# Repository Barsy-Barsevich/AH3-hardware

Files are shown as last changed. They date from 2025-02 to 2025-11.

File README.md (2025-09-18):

# AH3 hardware repository

- [AH3 on-board software repository](https://github.com/Barsy-Barsevich/AH3-software)
- [AH3 Arduino library](https://github.com/Barsy-Barsevich/AH3_Barsotion)

---
## ⚡️Manual
- [AH3 software 2nd revision manual (newest release)](./Manual/AH3_soft_revision_2_manual.pdf)
- [AH3 software 1st revision manual](./Manual/AH3_soft_revision_1_manual.pdf)
- [AH3 software 1st revision manual (preliminary edition)](./Manual/AH3_soft_revision_1_manual_preliminary_edition.pdf)

---
## ⚡️Previous AHx boards
- [AH1](https://github.com/Barsy-Barsevich/Barsotion-AH1)
- [AH2](https://github.com/Barsy-Barsevich/Barsotion-AH2)

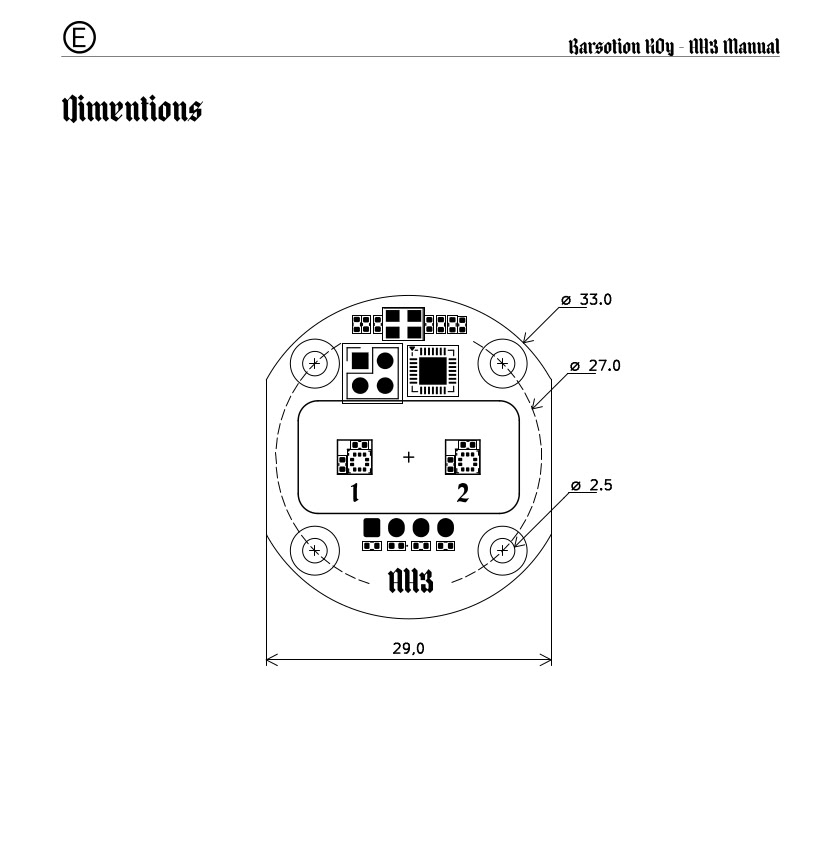
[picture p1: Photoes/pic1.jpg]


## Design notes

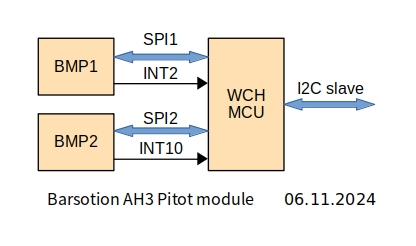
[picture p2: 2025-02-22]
Schematic/Barsotion_AH3_BlokScheme.jpg

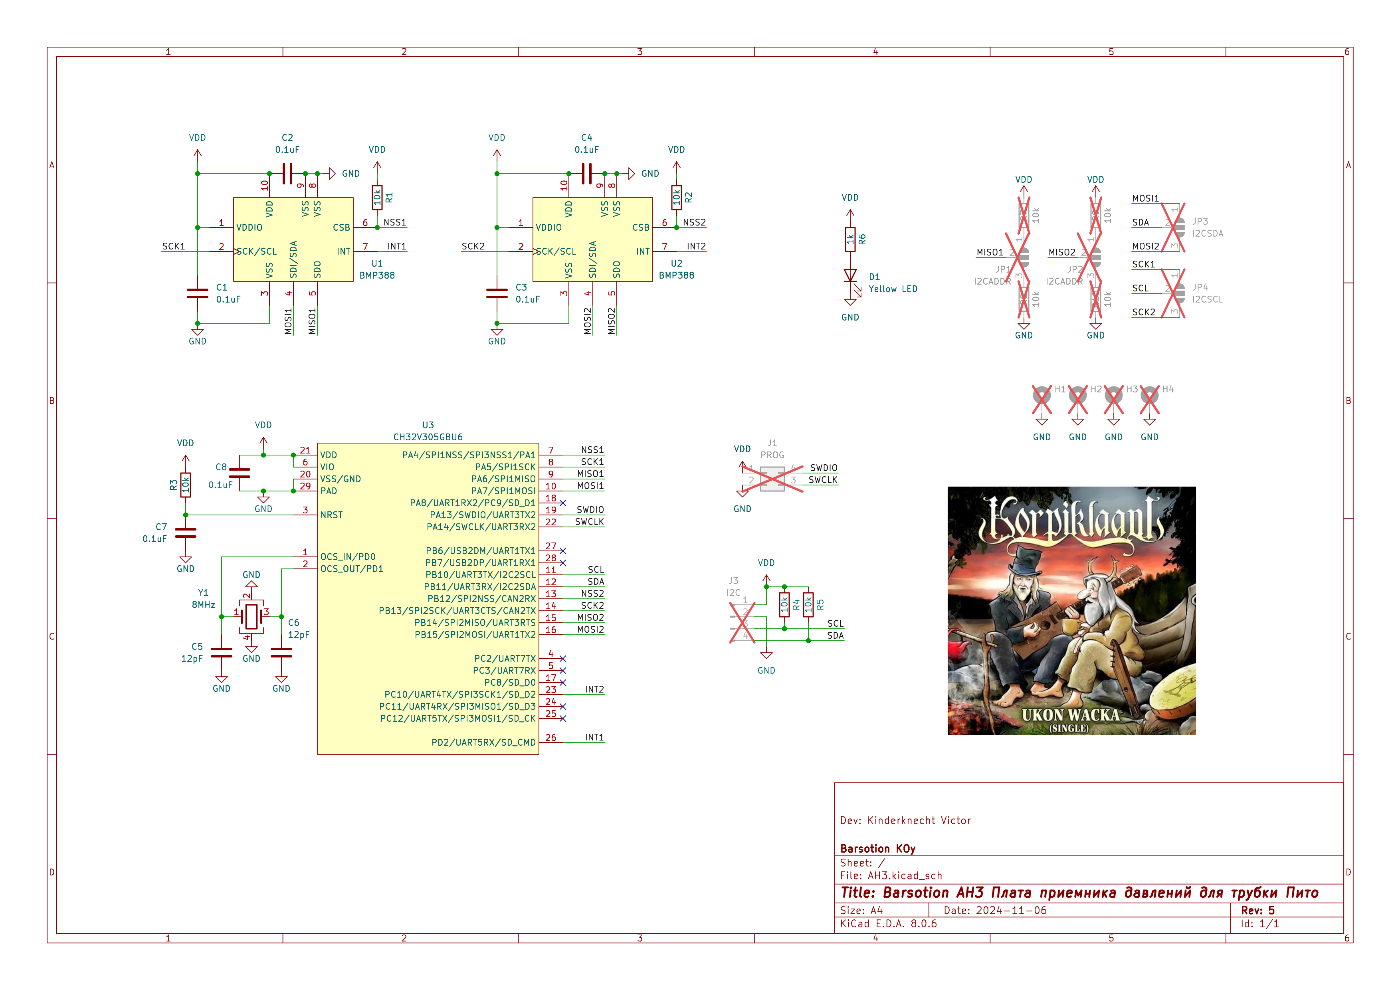
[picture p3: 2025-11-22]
Schematic/AH3v5_Schematic.png

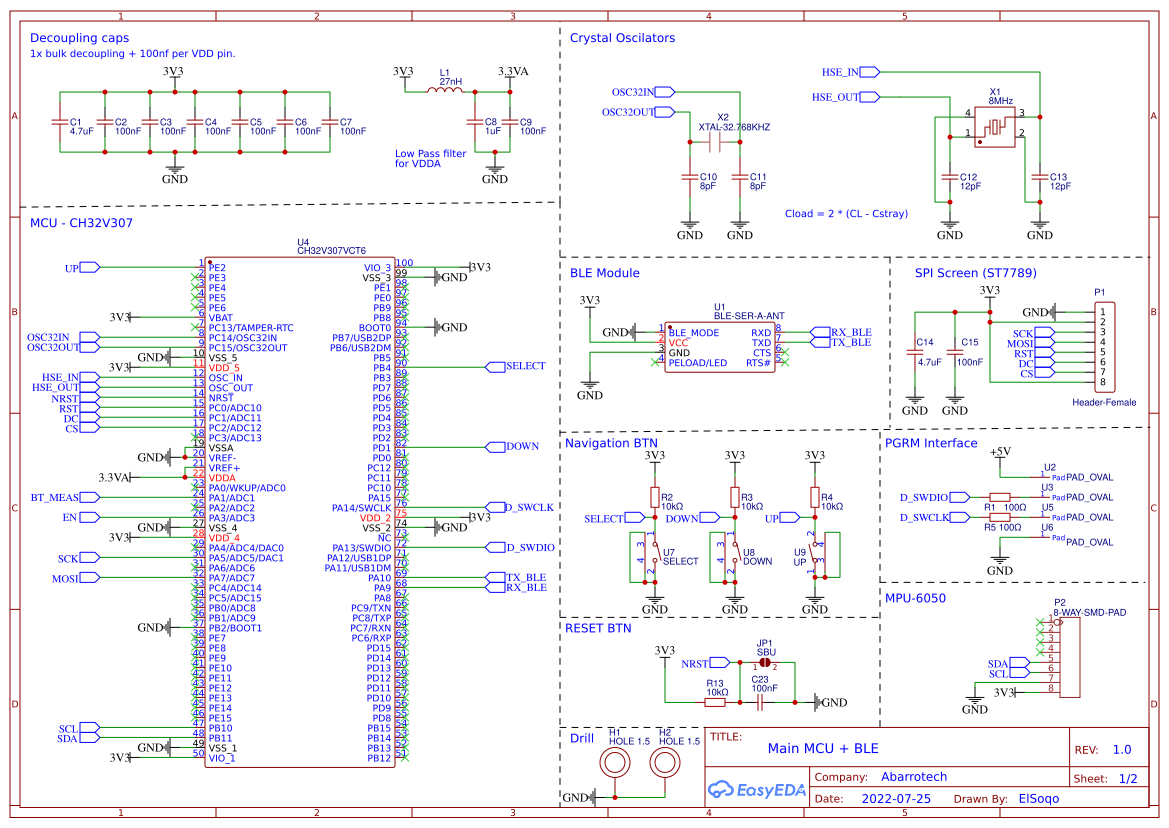
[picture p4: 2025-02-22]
Ref/CH32V307_REF1.png

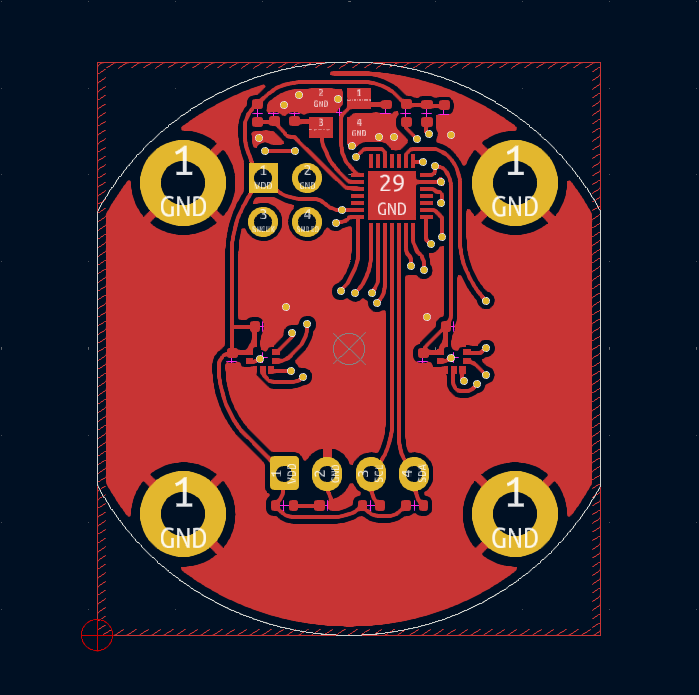
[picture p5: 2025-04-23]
Topology/AH3 Layer 1.png

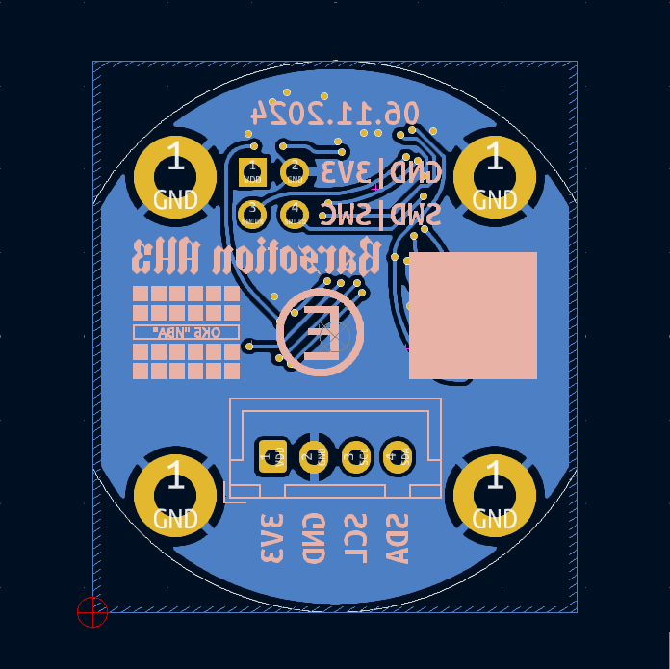
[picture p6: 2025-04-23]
Topology/AH3 Bottom.png

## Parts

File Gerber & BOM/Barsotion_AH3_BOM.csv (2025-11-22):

Reference | Value | Datasheet | Footprint | Qty | DNP
C1,C2,C3,C4,C7,C8 | 0.1uF | ~ | Capacitor_SMD:C_0402_1005Metric | 6
C5,C6 | 12pF | ~ | Capacitor_SMD:C_0402_1005Metric | 2
D1 | Yellow LED | ~ | LED_SMD:LED_0402_1005Metric | 1
R1,R2,R3,R4,R5 | 10k | ~ | Resistor_SMD:R_0402_1005Metric | 5
R6 | 1k | ~ | Resistor_SMD:R_0402_1005Metric | 1
U1,U2 | BMP388 | https://pdf1.alldatasheet.com/datasheet-pdf/download/1132070/BOSCH/BMP388.html | CustomPackage:BMP388 | 2
U3 | CH32V305GBU6 |  | Package_DFN_QFN:QFN-28-1EP_4x4mm_P0.4mm_EP2.8x2.8mm | 1
Y1 | 8MHz | https://www.lcsc.com/datasheet/lcsc_datasheet_2403291505_YXC-Crystal-Oscillators-X32258MOB4SI_C2682775.pdf | Crystal:Crystal_SMD_3225-4Pin_3.2x2.5mm | 1

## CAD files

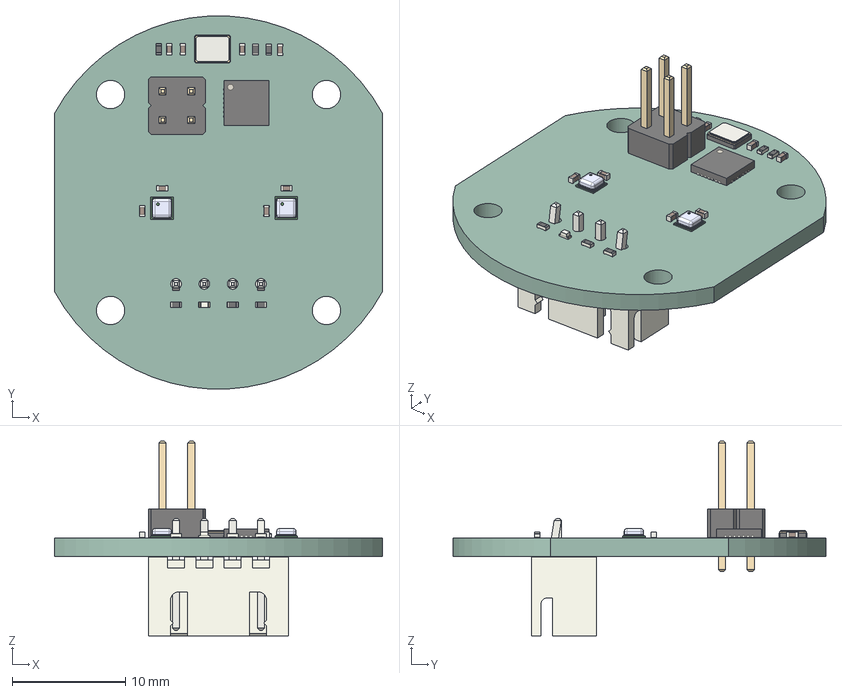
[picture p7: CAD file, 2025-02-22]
Step/AH3_v4.step
29.0 x 33.0 x 17.2 mm
QFN-28-1EP_4x4mm_Pitch0.4mm
C_0402_1005Metric x 8
R_0402_1005Metric x 6
BMP388 x 2
PinHeader_2x02_P254mm_Vertical
LED_0402_1005Metric
Crystal_SMD_3225-4Pin_3.2x2.5mm
JST_B4B_XH_A
AH3_PCB

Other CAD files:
Step/AH3_v2.step
Step/AH3_v01.step

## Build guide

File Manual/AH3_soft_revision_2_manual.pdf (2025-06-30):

## AH3 air speedometer module

## Software 2nd revision manual

Barsotion KOy, 2025

Barsotion KOy - AH3 Manual 2nd revision

## Table of contents

2

2

Barsotion KOy - AH3 Manual 2nd revision

## Overview

The Barsotion AH3 airspeed module is an I2C device created to measure atmosphere pressure, airspeed, vertical speed, altitude, air temperature.
This documents describes the work with the AH3 boards with the 1st version of processing microcontroller software.

Structural organization
The module contains 2 BMP388 temperature and pressure sensors and CH32V305 processing microcontroller. The microcontroller reads rata from the sensors via SPI, process it and can give the results to host via I2C interface.

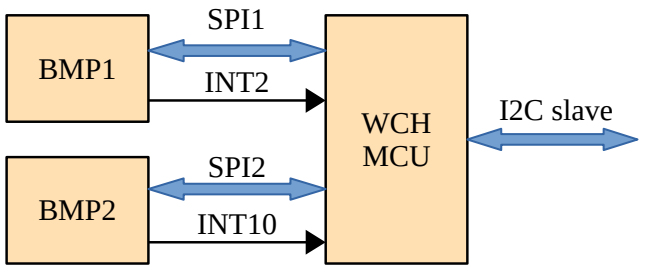
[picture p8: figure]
BMP1; BMP2; WCH MCU; SPI1; SPI2; I2C slave; INT2; INT10

The BMP388 sensors are numerated: 1 and 2. The 1st sensor is a static pressure and temperature sensor, the 2nd is a dynamic sensor.
The microcontroller process the data: it calculates altitude according the static sensor barometer data, differentiates altitude for getting vertical speed, also it can analyze the difference in static and dynamic pressures to get an air speed value. The read temperature and pressure data can be filtered by 1-dimentional Kalman filters. The calibration methods allows to get the filter start parameters and provide the quality of outgoing air speed data.

Future updates (TODO)
The host can set up the AH3 module depending of it’s needs. Both of static and dynamic sensors can be disabled if it is necessary. In this (1st) software version host cannot power down any BMP388 sensor, it will still work if even the according enable bit is cleared, so disabling the BMP388 sensor does not affect on the power consumption. However the sensor power down option while disabled will be added in future software versions.

3

Barsotion KOy - AH3 Manual 2nd revision

The BMP388 sensors interrupt request signals are wired to the microcontroller’s GPIOs. Theoretically, the data reading can be processed via interrupts, but this software does not use it. The program reads the BMP388s’ interrupt status registers waiting for the data ready bits setting up. The sensors interrupt handling will be added in future versions, that can also reduce the power consumption.

Sensors settings
The BMP388 maximum ODR value is 200 Hz. The processing microcontroller uses this ODR for providing fast reaction on the external events.
The software does not use the BMP388’s data oversampling function. The oversampling can help to get more accurate output value, however it strongly limits the real output data rate.
The software uses BMP388’s IIR-filter with coefficient 7. It is a compromise between data rate and accuracy.
The host cannot configure the BMP388 sensors settings for this software revision.

Applications
This airspeed module can be used in copters, model rockets, little airplanes, automobiles and other mobile machines and devices.

4

Barsotion KOy - AH3 Manual 2nd revision

## Device characteristics

Parameter | Min | Nom | Max
Power supply, V | 3.0 | 3.3 | 3.6
Power consimption, mA | - | - | 16
I2C logic level, V | - | 3.3 | 5
I2C speed, kHz | - | 400 | 1000
Main CPU frequency, MHz | - | 96 | -
BMP388 sensor ODR, Hz | - | 200 | -
Pressure oversampling | - | 1x | -
Temperature oversampling | - | 1x | -
BMP388 IIR-filter coefficient | - | 7 | -

5

Barsotion KOy - AH3 Manual 2nd revision

## Register map

Name | Address | Description
WHO_AM_I | 0x00 | Always read as 0x74.
SOFT_REV | 0x01 | Soft revision code, for this version 0x02.
ERR | 0x02 | Error status register, see ERR.
CONFIG | 0x03 | Config register, see CONFIG.
STATUS | 0x04 | Status flag register, see STATUS.
TEMP1_0 | 0x05 | Static sensor temperature data, 4-byte float.
TEMP1_1 | 0x06
TEMP1_2 | 0x07
TEMP1_3 | 0x08
PRES1_0 | 0x09 | Static sensor pressure data, 4-byte float.
PRES1_1 | 0x0A
PRES1_2 | 0x0B
PRES1_3 | 0x0C
TEMP2_0 | 0x0D | Dynamic sensor temperature data, 4-byte float.
TEMP2_1 | 0x0E
TEMP2_2 | 0x0F
TEMP2_3 | 0x10
PRES2_0 | 0x11 | Dynamic sensor pressure data, 4-byte float.
PRES2_1 | 0x12
PRES2_2 | 0x13
PRES2_3 | 0x14
ASPEED_0 | 0x15 | Calculated air speed value, 4-byte float.
ASPEED_1 | 0x16
ASPEED_2 | 0x17
ASPEED_3 | 0x18
ALT_0 | 0x19 | Calculated altitude.
ALT_1 | 0x1A
ALT_2 | 0x1B
ALT_3 | 0x1C

6

Barsotion KOy - AH3 Manual 2nd revision

VSPEED_0 | 0x1D | Calculated vertical speed.
VSPEED_1 | 0x1E
VSPEED_2 | 0x1F
VSPEED_3 | 0x20
WHO_AM_I
7 | 6 | 5 | 4 | 3 | 2 | 1 | 0
0 | 1 | 1 | 1 | 0 | 1 | 0 | 0
The register is always read as 0x74.
SOFT_REV
7 | 6 | 5 | 4 | 3 | 2 | 1 | 0
0 | 0 | 0 | 0 | 0 | 0 | 0 | 1
The register is always read as 0x01.
ERR
7 | 6 | 5 | 4 | 3 | 2 | 1 | 0
Reserved | | | ERR_BMP2 _DATA | ERR_BMP1 _DATA | ERR_I2C | ERR_BMP2 _INIT | ERR_BMP1 _INIT
- ERR_BMP1_INIT: Static sensor initialization error.
- ERR_BMP2_INIT: Dynamic sensor initialization error.
- ERR_I2C: I2C protocol error.
- ERR_BMP1_DATA: Static sensor data incorrect value error (is not supported in this version).
- ERR_BMP2_DATA: Dynamic sensor data incorrect value error (is not supported in this version).
CONFIG
7 | 6 | 5 | 4 | 3 | 2 | 1 | 0
ASPD_CAL | ASPD_EN | BMP2_CAL | BMP1_CAL | BMP2_FILT | BMP1_FILT | BMP2_EN | BMP1_EN
- BMP1_EN: Set to 1 enables static sensor data reading.
- BMP2_EN: Set to 1 enables dynamic sensor data reading.
- BMP1_FILT: Set to 1 enables static sensor data filtering by 1-dimentional Kalman algorithm (the option is available only after calibrating).
- BMP2_FILT: Set to 1 enables dynamic sensor data filtering by 1-dimentional Kalman algorithm (the option is available only after calibrating).
- BMP1_CAL: Set to starts static sensor calibration. Cleared automatically after the calibration has finished. While the calibration time goes on, the BUSY bit in STATUS register is set to 1.

7

Barsotion KOy - AH3 Manual 2nd revision

- BMP2_CAL: Set to starts dynamic sensor calibration. Cleared automatically after the calibration has finished. While the calibration time goes on, the BUSY bit in STATUS register is set to 1.
- ASPD_EN: Set to 1 enables air speed calculations. The option is only available if both of BMP1_EN and BMP2_EN bits are set to 1. Note that the barometer sensors should be calibrated before air speed calculations starts, in the other way the output data will contain a non-normed offset.
- ASPD_CAL: Set to 1 starts the airspeed calibrating.
STATUS
7 | 6 | 5 | 4 | 3 | 2 | 1 | 0
BUSY | ASPD_DRDY | Reserved | | | | BMP2_DRDY | BMP1_DRDY
- BMP1_DRDY: is set to 1 when the first sensor temperature and pressure data are ready to be read. The bit is cleared automatically when the STATUS register is read.
- BMP2_DRDY: is set to 1 when the second sensor temperature and pressure data are ready to be read. The bit is cleared automatically when the STATUS register is read.
- ASPD_DRDY: is set to 1 when the air speed value is ready to be read. The bit is cleared automatically when the STATUS register is read.
- BUSY: is set when any sensor is calibrating. While the calibrating time the AH3 module do not update other sensor output data and air speed calculations are stopped too. The bit is cleared automatically when the calibration done.
Output data format
All the output data are in the standard IEEE-754 4-byte float format, used in the C language. That means:
0

th register:
7 | 6 | 5 | 4 | 3 | 2 | 1 | 0
Mantissa | | | | | | | Man. LSb
1

st register:
15 | 14 | 13 | 12 | 11 | 10 | 8 | 7
Mantissa
2

nd register:
23 | 22 | 21 | 20 | 19 | 18 | 17 | 16
Exp. LSb | Man. MSb | Mantissa
3

rd register:
31 | 30 | 29 | 28 | 27 | 26 | 25 | 24
Sign | Exp. MSb | Exponent

8

Barsotion KOy - AH3 Manual 2nd revision

## Initialization algorithm (air speed calculation enable)

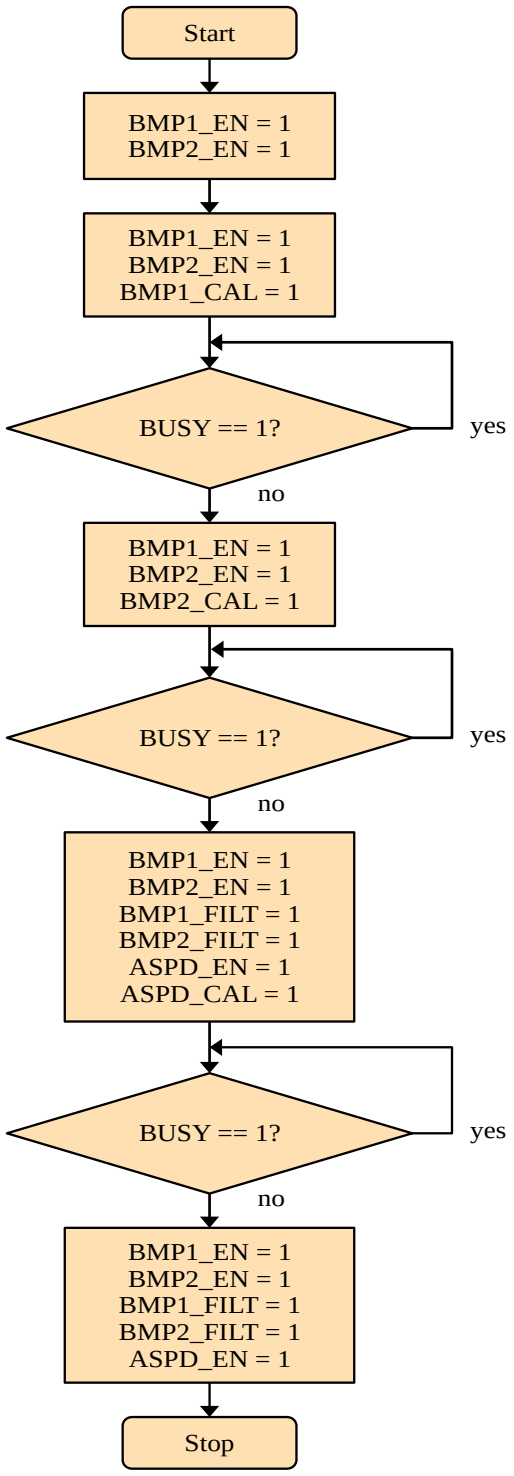
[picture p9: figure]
BMP1_EN = 1 BMP2_EN = 1; BMP1_EN = 1 BMP2_EN = 1 BMP1_CAL = 1; BUSY == 1?; BMP1_EN = 1 BMP2_EN = 1 BMP2_CAL = 1; BMP1_EN = 1 BMP2_EN = 1 BMP1_FILT = 1 BMP2_FILT = 1 ASPD_EN = 1 ASPD_CAL = 1; BMP1_EN = 1 BMP2_EN = 1 BMP1_FILT = 1 BMP2_FILT = 1 ASPD_EN = 1; yes; Start; Stop

9

## Dimentions

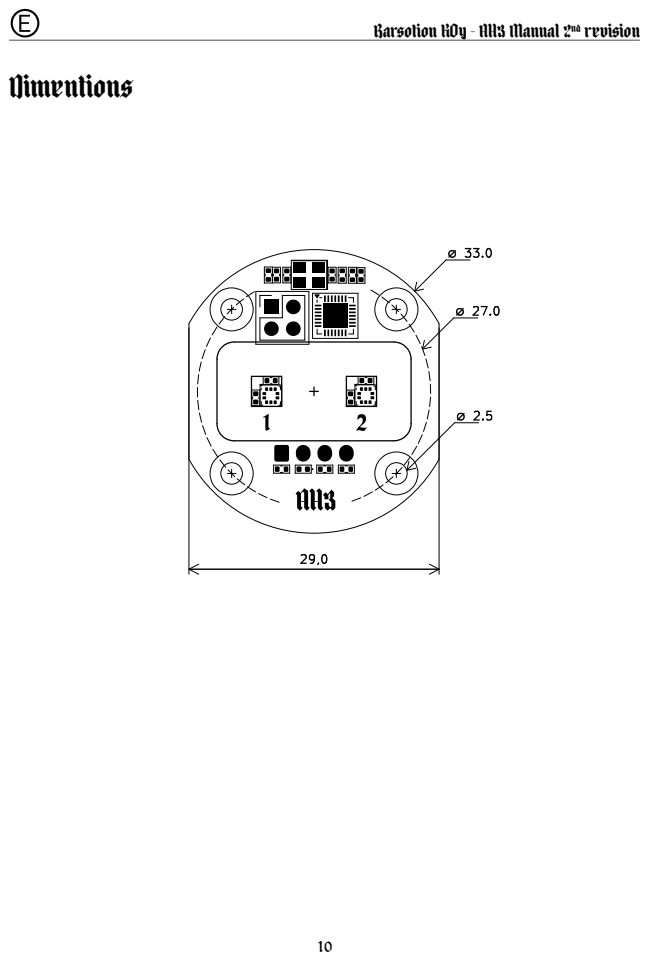
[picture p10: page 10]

Barsotion KOy - AH3 Manual 2nd revision

2

## nd revision

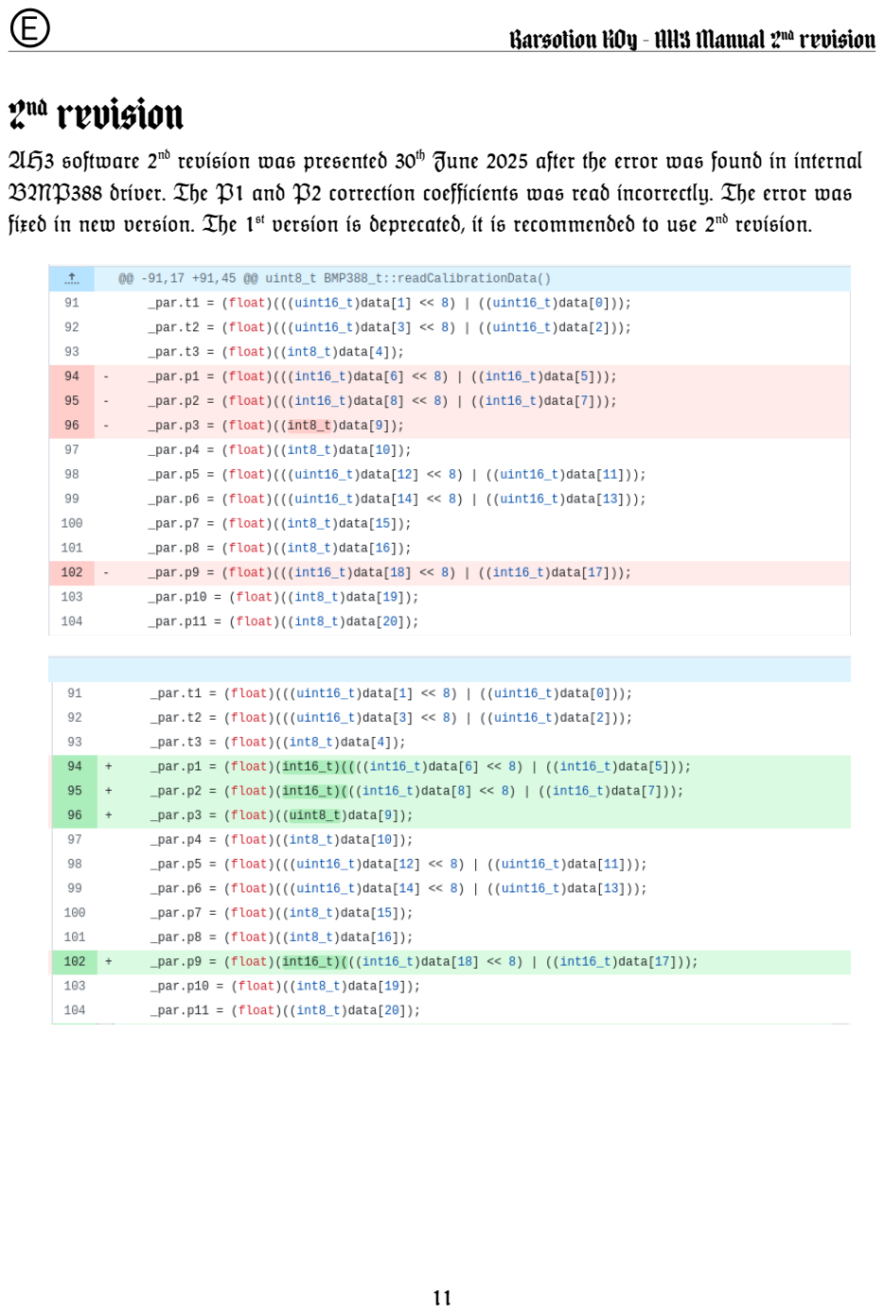
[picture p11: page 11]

Barsotion KOy - AH3 Manual 2nd revision

AH3 software 2nd revision was presented 30th June 2025 after the error was found in internal BMP388 driver. The P1 and P2 correction coefficients was read incorrectly. The error was fixed in new version. The 1st version is deprecated, it is recommended to use 2nd revision.

11

Barsotion KOy - AH3 Manual 2nd revision

## Revision history

Date | Modification
Jun 30, 2025 | BMP388 driver bug fixed.
Mar 8, 2025 | New dimention picture, revision history addition.
Jan 21, 2025 | Document creation.

12

Barsotion KOy - AH3 Manual 2nd revision

## Contacts

If you have any questions, feel free to write via email or Telegram. Email: barsotion@yandex.ru
Telegram: @barsybarsevich

13

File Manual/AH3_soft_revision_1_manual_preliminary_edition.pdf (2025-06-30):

## AH3 air speedometer module

## Software 1st revision manual

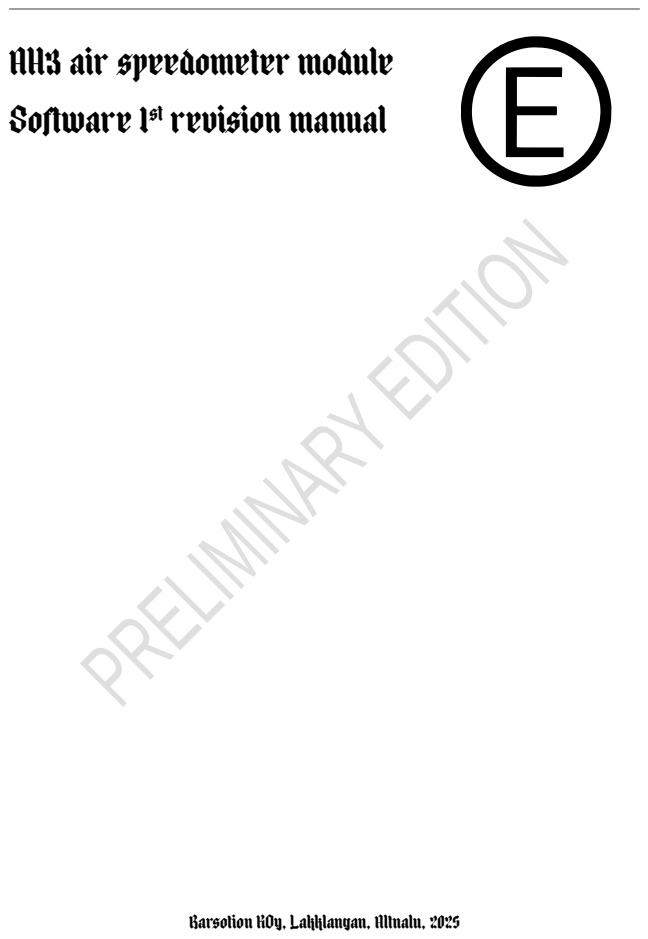
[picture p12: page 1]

Barsotion KOy, Lakklangan, Altnalu, 2025

## Table of contents

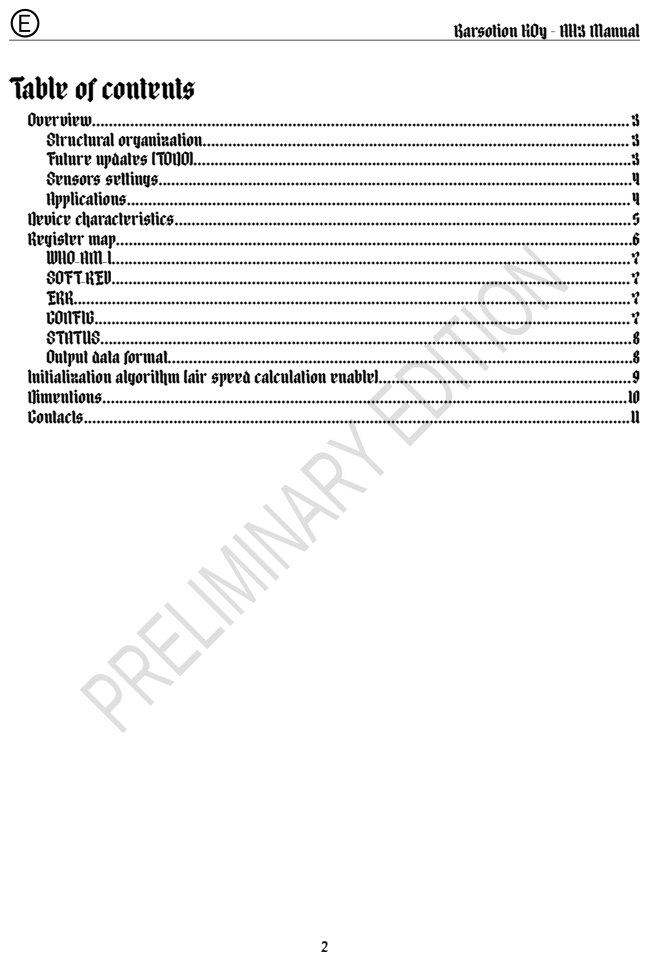
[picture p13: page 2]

Barsotion KOy - AH3 Manual

Barsotion KOy - AH3 Manual

## Overview

The Barsotion AH3 airspeed module is an I2C device created to measure atmosphere pressure, airspeed, vertical speed, altitude, air temperature.
This documents describes the work with the AH3 boards with the 1st version of processing microcontroller software.

Structural organization
The module contains 2 BMP388 temperature and pressure sensors and CH32V305 processing microcontroller. The microcontroller reads rata from the sensors via SPI, process it and can give the results to host via I2C interface.

The BMP388 sensors are numerated: 1 and 2. The 1st sensor is a static pressure and temperature sensor, the 2nd is a dynamic sensor.
The microcontroller process the data: it calculates altitude according the static sensor barometer data, differentiates altitude for getting vertical speed, also it can analyze the difference in static and dynamic pressures to get an air speed value. The read temperature and pressure data can be filtered by 1-dimentional Kalman filters. The calibration methods allows to get the filter start parameters and provide the quality of outgoing air speed data.

Future updates (TODO)
The host can set up the AH3 module depending of it’s needs. Both of static and dynamic sensors can be disabled if it is necessary. In this (1st) software version host cannot power down any BMP388 sensor, it will still work if even the according enable bit is cleared, so disabling the BMP388 sensor does not affect on the power consumption. However the sensor power down option while disabled will be added in future software versions.

3

BMP1

BMP2

WCH
MCU

SPI1

SPI2

I2C slave

INT2

INT10

Barsotion KOy - AH3 Manual

The BMP388 sensors interrupt request signals are wired to the microcontroller’s GPIOs. Theoretically, the data reading can be processed via interrupts, but this software does not use it. The program reads the BMP388s’ interrupt status registers waiting for the data ready bits setting up. The sensors interrupt handling will be added in future versions, that can also reduce the power consumption.

Sensors settings
The BMP388 maximum ODR value is 200 Hz. The processing microcontroller uses this ODR for providing fast reaction on the external events.
The software does not use the BMP388’s data oversampling function. The oversampling can help to get more accurate output value, however it strongly limits the real output data rate.
The software uses BMP388’s IIR-filter with coefficient 7. It is a compromise between data rate and accuracy.
The host cannot configure the BMP388 sensors settings for this software revision.

Applications
This airspeed module can be used in copters, model rockets, little airplanes, automobiles and other mobile machines and devices.

4

## Device characteristics

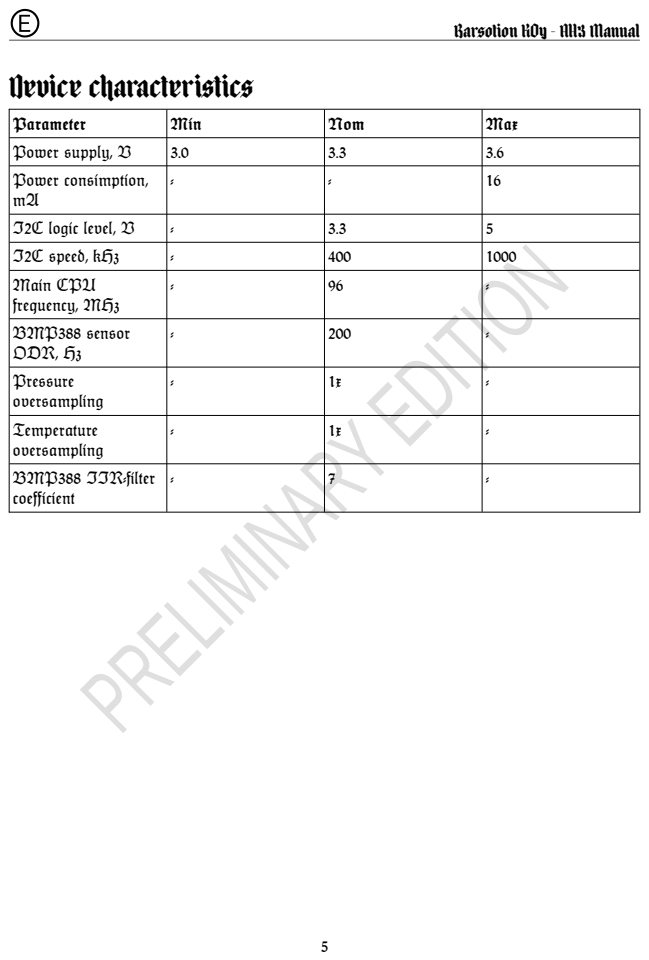
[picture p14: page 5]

Barsotion KOy - AH3 Manual

Parameter | Min | Nom | Max
Power supply, V | 3.0 | 3.3 | 3.6
Power consimption, mA | - | - | 16

I2C logic level, V | - | 3.3 | 5
I2C speed, kHz | - | 400 | 1000
Main CPU frequency, MHz | - | 96 | -

BMP388 sensor ODR, Hz | - | 200 | -

Pressure oversampling | - | 1x | -

Temperature oversampling | - | 1x | -

BMP388 IIR-filter coefficient | - | 7 | -

## Register map

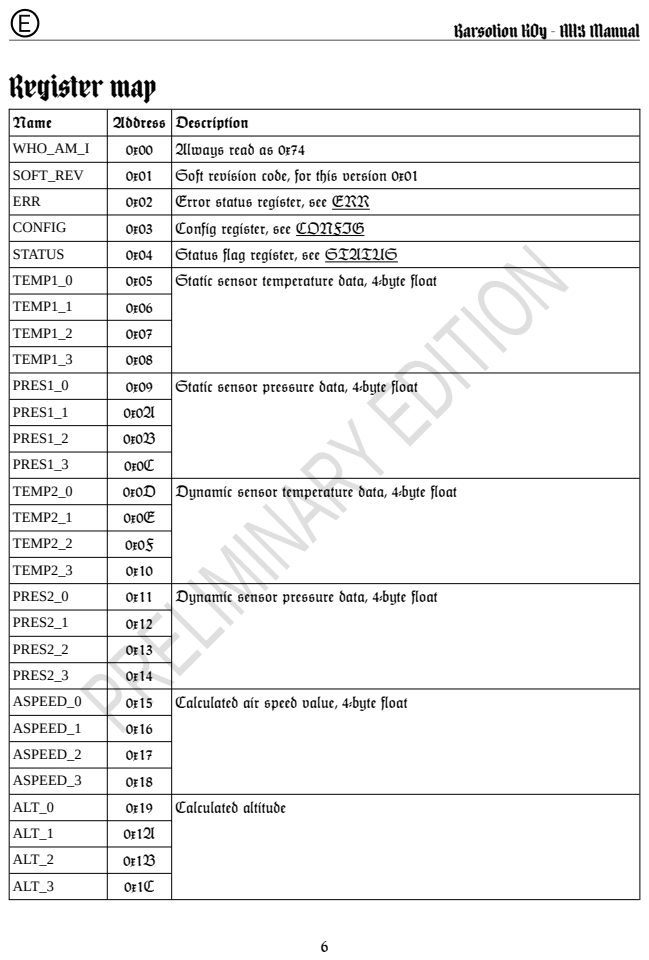
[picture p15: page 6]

Barsotion KOy - AH3 Manual

Name | Address | Description
WHO_AM_I | 0x00 | Always read as 0x74
SOFT_REV | 0x01 | Soft revision code, for this version 0x01
ERR | 0x02 | Error status register, see ERR
CONFIG | 0x03 | Config register, see CONFIG
STATUS | 0x04 | Status flag register, see STATUS
TEMP1_0 | 0x05 | Static sensor temperature data, 4-byte float
TEMP1_1 | 0x06
TEMP1_2 | 0x07
TEMP1_3 | 0x08
PRES1_0 | 0x09 | Static sensor pressure data, 4-byte float
PRES1_1 | 0x0A
PRES1_2 | 0x0B
PRES1_3 | 0x0C
TEMP2_0 | 0x0D | Dynamic sensor temperature data, 4-byte float
TEMP2_1 | 0x0E
TEMP2_2 | 0x0F
TEMP2_3 | 0x10
PRES2_0 | 0x11 | Dynamic sensor pressure data, 4-byte float
PRES2_1 | 0x12
PRES2_2 | 0x13
PRES2_3 | 0x14
ASPEED_0 | 0x15 | Calculated air speed value, 4-byte float
ASPEED_1 | 0x16
ASPEED_2 | 0x17
ASPEED_3 | 0x18
ALT_0 | 0x19 | Calculated altitude
ALT_1 | 0x1A
ALT_2 | 0x1B
ALT_3 | 0x1C

Barsotion KOy - AH3 Manual

VSPEED_0 | 0x1D | Calculated vertical speed
VSPEED_1 | 0x1E
VSPEED_2 | 0x1F
VSPEED_3 | 0x20
WHO_AM_I
7 | 6 | 5 | 4 | 3 | 2 | 1 | 0
0 | 1 | 1 | 1 | 0 | 1 | 0 | 0
The register is always read as 0x74.
SOFT_REV
7 | 6 | 5 | 4 | 3 | 2 | 1 | 0
0 | 0 | 0 | 0 | 0 | 0 | 0 | 1
The register is always read as 0x01.
ERR
7 | 6 | 5 | 4 | 3 | 2 | 1 | 0
Reserved | | | ERR_BMP2 _DATA | ERR_BMP1 _DATA | ERR_I2C | ERR_BMP2 _INIT | ERR_BMP1 _INIT
- ERR_BMP1_INIT: Static sensor initialization error.
- ERR_BMP2_INIT: Dynamic sensor initialization error.
- ERR_I2C: I2C protocol error.
- ERR_BMP1_DATA: Static sensor data incorrect value error (is not supported in this version).
- ERR_BMP2_DATA: Dynamic sensor data incorrect value error (is not supported in this version).
CONFIG
7 | 6 | 5 | 4 | 3 | 2 | 1 | 0
ASPD_CAL | ASPD_EN | BMP2_CAL | BMP1_CAL | BMP2_FILT | BMP1_FILT | BMP2_EN | BMP1_EN
- BMP1_EN: Set to 1 enables static sensor data reading.
- BMP2_EN: Set to 1 enables dynamic sensor data reading.
- BMP1_FILT: Set to 1 enables static sensor data filtering by 1-dimentional Kalman algorithm (the option is available only after calibrating).
- BMP2_FILT: Set to 1 enables dynamic sensor data filtering by 1-dimentional Kalman algorithm (the option is available only after calibrating).
- BMP1_CAL: Set to starts static sensor calibration. Cleared automatically after the calibration has finished. While the calibration time goes on, the BUSY bit in STATUS register is set to 1.

7

Barsotion KOy - AH3 Manual

- BMP2_CAL: Set to starts dynamic sensor calibration. Cleared automatically after the calibration has finished. While the calibration time goes on, the BUSY bit in STATUS register is set to 1.
- ASPD_EN: Set to 1 enables air speed calculations. The option is only available if both of BMP1_EN and BMP2_EN bits are set to 1. Note that the barometer sensors should be calibrated before air speed calculations starts, in the other way the output data will contain a non-normed offset.
- ASPD_CAL: Set to 1 starts the airspeed calibrating.
STATUS
7 | 6 | 5 | 4 | 3 | 2 | 1 | 0
BUSY | ASPD_DRDY | Reserved | | | | BMP2_DRDY | BMP1_DRDY
- BMP1_DRDY: is set to 1 when the first sensor temperature and pressure data are ready to be read. The bit is cleared automatically when the STATUS register is read.
- BMP2_DRDY: is set to 1 when the second sensor temperature and pressure data are ready to be read. The bit is cleared automatically when the STATUS register is read.
- ASPD_DRDY: is set to 1 when the air speed value is ready to be read. The bit is cleared automatically when the STATUS register is read.
- BUSY: is set when any sensor is calibrating. While the calibrating time the AH3 module do not update other sensor output data and air speed calculations are stopped too. The bit is cleared automatically when the calibration done.
Output data format
All the output data are in the standard IEEE-754 4-byte float format, used in the C language. That means:
0

th register:
7 | 6 | 5 | 4 | 3 | 2 | 1 | 0
Mantissa | | | | | | | Man. LSb
1

st register:
15 | 14 | 13 | 12 | 11 | 10 | 8 | 7
Mantissa
2

nd register:
23 | 22 | 21 | 20 | 19 | 18 | 17 | 16
Exp. LSb | Man. MSb | Mantissa
3

rd register:
31 | 30 | 29 | 28 | 27 | 26 | 25 | 24
Sign | Exp. MSb | Exponent

8

## Initialization algorithm (air speed calculation enable)

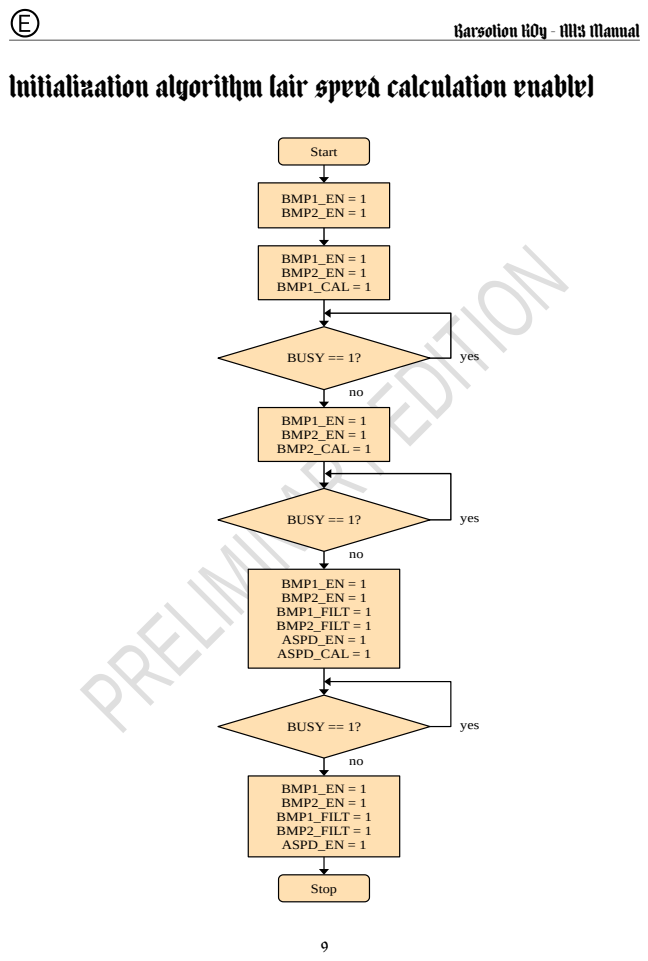
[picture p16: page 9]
BMP1_EN = 1 BMP2_EN = 1; BMP1_EN = 1 BMP2_EN = 1 BMP1_CAL = 1; BUSY == 1?; BMP1_EN = 1 BMP2_EN = 1 BMP2_CAL = 1; BMP1_EN = 1 BMP2_EN = 1 BMP1_FILT = 1 BMP2_FILT = 1 ASPD_EN = 1 ASPD_CAL = 1; BMP1_EN = 1 BMP2_EN = 1 BMP1_FILT = 1 BMP2_FILT = 1 ASPD_EN = 1; yes; Start; Stop

Barsotion KOy - AH3 Manual

## Dimentions

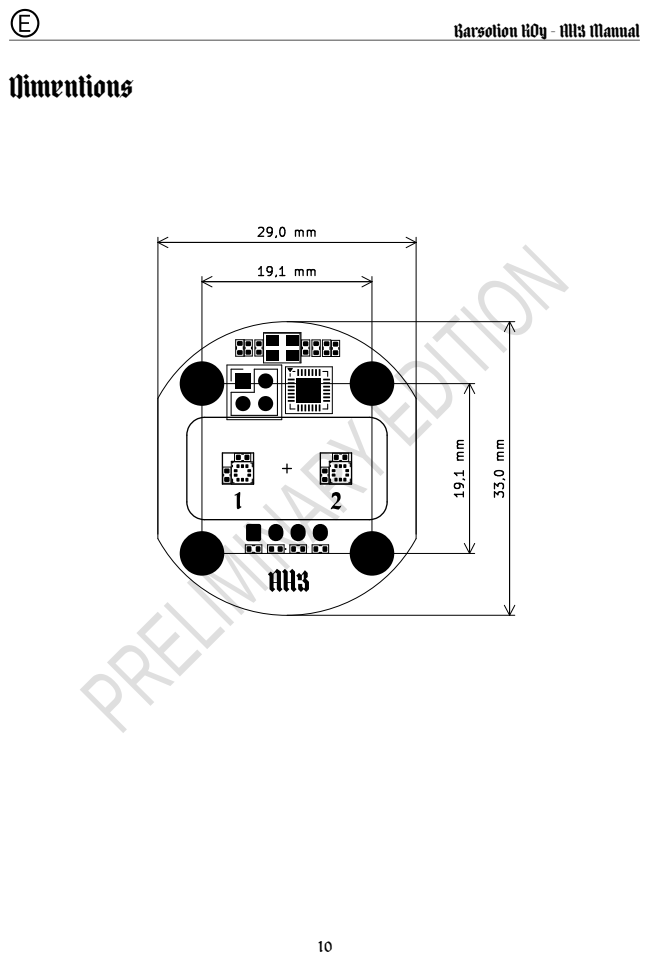
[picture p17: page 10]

Barsotion KOy - AH3 Manual

## Contacts

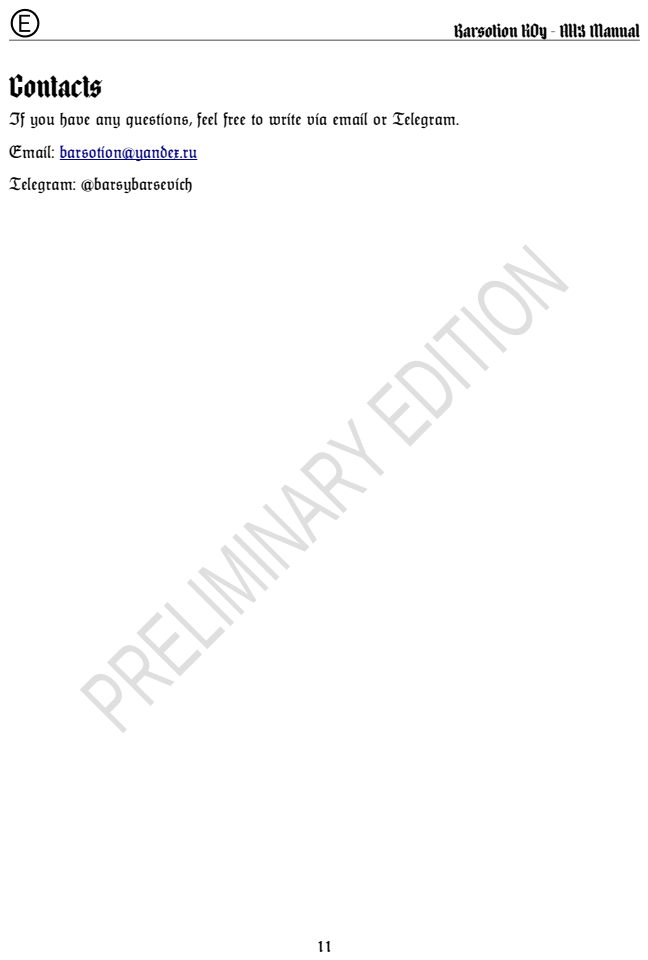
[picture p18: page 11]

Barsotion KOy - AH3 Manual

If you have any questions, feel free to write via email or Telegram.
Email: barsotion@yandex.ru
Telegram: @barsybarsevich

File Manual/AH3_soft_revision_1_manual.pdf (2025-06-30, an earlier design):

## AH3 air speedometer module

## Software 1st revision manual

Barsotion KOy, 2025

Barsotion KOy - AH3 Manual

## Table of contents

2

Barsotion KOy - AH3 Manual

## Overview

The Barsotion AH3 airspeed module is an I2C device created to measure atmosphere pressure, airspeed, vertical speed, altitude, air temperature.
This documents describes the work with the AH3 boards with the 1st version of processing microcontroller software.

Structural organization
The module contains 2 BMP388 temperature and pressure sensors and CH32V305 processing microcontroller. The microcontroller reads rata from the sensors via SPI, process it and can give the results to host via I2C interface.

BMP1; BMP2; WCH MCU; SPI1; SPI2; I2C slave; INT2; INT10

The BMP388 sensors are numerated: 1 and 2. The 1st sensor is a static pressure and temperature sensor, the 2nd is a dynamic sensor.
The microcontroller process the data: it calculates altitude according the static sensor barometer data, differentiates altitude for getting vertical speed, also it can analyze the difference in static and dynamic pressures to get an air speed value. The read temperature and pressure data can be filtered by 1-dimentional Kalman filters. The calibration methods allows to get the filter start parameters and provide the quality of outgoing air speed data.

Future updates (TODO)
The host can set up the AH3 module depending of it’s needs. Both of static and dynamic sensors can be disabled if it is necessary. In this (1st) software version host cannot power down any BMP388 sensor, it will still work if even the according enable bit is cleared, so disabling the BMP388 sensor does not affect on the power consumption. However the sensor power down option while disabled will be added in future software versions.

3

Barsotion KOy - AH3 Manual

The BMP388 sensors interrupt request signals are wired to the microcontroller’s GPIOs. Theoretically, the data reading can be processed via interrupts, but this software does not use it. The program reads the BMP388s’ interrupt status registers waiting for the data ready bits setting up. The sensors interrupt handling will be added in future versions, that can also reduce the power consumption.

Sensors settings
The BMP388 maximum ODR value is 200 Hz. The processing microcontroller uses this ODR for providing fast reaction on the external events.
The software does not use the BMP388’s data oversampling function. The oversampling can help to get more accurate output value, however it strongly limits the real output data rate.
The software uses BMP388’s IIR-filter with coefficient 7. It is a compromise between data rate and accuracy.
The host cannot configure the BMP388 sensors settings for this software revision.

Applications
This airspeed module can be used in copters, model rockets, little airplanes, automobiles and other mobile machines and devices.

4

Barsotion KOy - AH3 Manual

## Device characteristics

Parameter | Min | Nom | Max
Power supply, V | 3.0 | 3.3 | 3.6
Power consimption, mA | - | - | 16
I2C logic level, V | - | 3.3 | 5
I2C speed, kHz | - | 400 | 1000
Main CPU frequency, MHz | - | 96 | -
BMP388 sensor ODR, Hz | - | 200 | -
Pressure oversampling | - | 1x | -
Temperature oversampling | - | 1x | -
BMP388 IIR-filter coefficient | - | 7 | -

5

Barsotion KOy - AH3 Manual

## Register map

Name | Address | Description
WHO_AM_I | 0x00 | Always read as 0x74
SOFT_REV | 0x01 | Soft revision code, for this version 0x01
ERR | 0x02 | Error status register, see ERR
CONFIG | 0x03 | Config register, see CONFIG
STATUS | 0x04 | Status flag register, see STATUS
TEMP1_0 | 0x05 | Static sensor temperature data, 4-byte float
TEMP1_1 | 0x06
TEMP1_2 | 0x07
TEMP1_3 | 0x08
PRES1_0 | 0x09 | Static sensor pressure data, 4-byte float
PRES1_1 | 0x0A
PRES1_2 | 0x0B
PRES1_3 | 0x0C
TEMP2_0 | 0x0D | Dynamic sensor temperature data, 4-byte float
TEMP2_1 | 0x0E
TEMP2_2 | 0x0F
TEMP2_3 | 0x10
PRES2_0 | 0x11 | Dynamic sensor pressure data, 4-byte float
PRES2_1 | 0x12
PRES2_2 | 0x13
PRES2_3 | 0x14
ASPEED_0 | 0x15 | Calculated air speed value, 4-byte float
ASPEED_1 | 0x16
ASPEED_2 | 0x17
ASPEED_3 | 0x18
ALT_0 | 0x19 | Calculated altitude
ALT_1 | 0x1A
ALT_2 | 0x1B
ALT_3 | 0x1C

6

Barsotion KOy - AH3 Manual

VSPEED_0 | 0x1D | Calculated vertical speed
VSPEED_1 | 0x1E
VSPEED_2 | 0x1F
VSPEED_3 | 0x20
WHO_AM_I
7 | 6 | 5 | 4 | 3 | 2 | 1 | 0
0 | 1 | 1 | 1 | 0 | 1 | 0 | 0
The register is always read as 0x74.
SOFT_REV
7 | 6 | 5 | 4 | 3 | 2 | 1 | 0
0 | 0 | 0 | 0 | 0 | 0 | 0 | 1
The register is always read as 0x01.
ERR
7 | 6 | 5 | 4 | 3 | 2 | 1 | 0
Reserved | | | ERR_BMP2 _DATA | ERR_BMP1 _DATA | ERR_I2C | ERR_BMP2 _INIT | ERR_BMP1 _INIT
- ERR_BMP1_INIT: Static sensor initialization error.
- ERR_BMP2_INIT: Dynamic sensor initialization error.
- ERR_I2C: I2C protocol error.
- ERR_BMP1_DATA: Static sensor data incorrect value error (is not supported in this version).
- ERR_BMP2_DATA: Dynamic sensor data incorrect value error (is not supported in this version).
CONFIG
7 | 6 | 5 | 4 | 3 | 2 | 1 | 0
ASPD_CAL | ASPD_EN | BMP2_CAL | BMP1_CAL | BMP2_FILT | BMP1_FILT | BMP2_EN | BMP1_EN
- BMP1_EN: Set to 1 enables static sensor data reading.
- BMP2_EN: Set to 1 enables dynamic sensor data reading.
- BMP1_FILT: Set to 1 enables static sensor data filtering by 1-dimentional Kalman algorithm (the option is available only after calibrating).
- BMP2_FILT: Set to 1 enables dynamic sensor data filtering by 1-dimentional Kalman algorithm (the option is available only after calibrating).
- BMP1_CAL: Set to starts static sensor calibration. Cleared automatically after the calibration has finished. While the calibration time goes on, the BUSY bit in STATUS register is set to 1.

7

Barsotion KOy - AH3 Manual

- BMP2_CAL: Set to starts dynamic sensor calibration. Cleared automatically after the calibration has finished. While the calibration time goes on, the BUSY bit in STATUS register is set to 1.
- ASPD_EN: Set to 1 enables air speed calculations. The option is only available if both of BMP1_EN and BMP2_EN bits are set to 1. Note that the barometer sensors should be calibrated before air speed calculations starts, in the other way the output data will contain a non-normed offset.
- ASPD_CAL: Set to 1 starts the airspeed calibrating.
STATUS
7 | 6 | 5 | 4 | 3 | 2 | 1 | 0
BUSY | ASPD_DRDY | Reserved | | | | BMP2_DRDY | BMP1_DRDY
- BMP1_DRDY: is set to 1 when the first sensor temperature and pressure data are ready to be read. The bit is cleared automatically when the STATUS register is read.
- BMP2_DRDY: is set to 1 when the second sensor temperature and pressure data are ready to be read. The bit is cleared automatically when the STATUS register is read.
- ASPD_DRDY: is set to 1 when the air speed value is ready to be read. The bit is cleared automatically when the STATUS register is read.
- BUSY: is set when any sensor is calibrating. While the calibrating time the AH3 module do not update other sensor output data and air speed calculations are stopped too. The bit is cleared automatically when the calibration done.
Output data format
All the output data are in the standard IEEE-754 4-byte float format, used in the C language. That means:
0

th register:
7 | 6 | 5 | 4 | 3 | 2 | 1 | 0
Mantissa | | | | | | | Man. LSb
1

st register:
15 | 14 | 13 | 12 | 11 | 10 | 8 | 7
Mantissa
2

nd register:
23 | 22 | 21 | 20 | 19 | 18 | 17 | 16
Exp. LSb | Man. MSb | Mantissa
3

rd register:
31 | 30 | 29 | 28 | 27 | 26 | 25 | 24
Sign | Exp. MSb | Exponent

8

Barsotion KOy - AH3 Manual

## Initialization algorithm (air speed calculation enable)

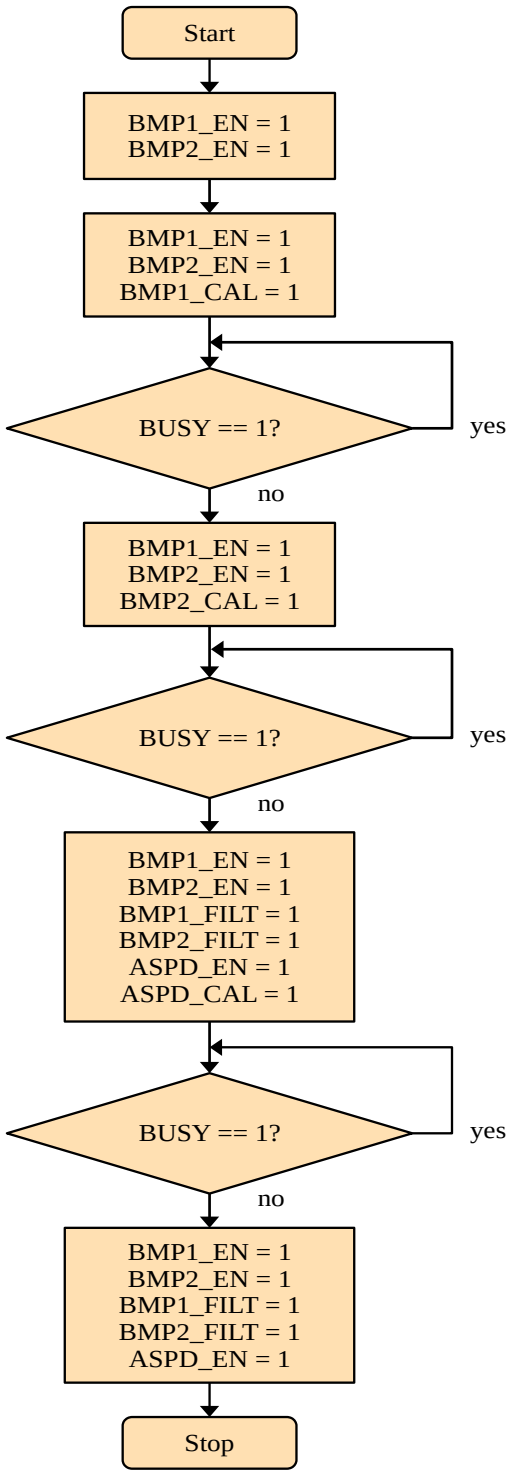
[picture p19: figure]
BMP1_EN = 1 BMP2_EN = 1; BMP1_EN = 1 BMP2_EN = 1 BMP1_CAL = 1; BUSY == 1?; BMP1_EN = 1 BMP2_EN = 1 BMP2_CAL = 1; BMP1_EN = 1 BMP2_EN = 1 BMP1_FILT = 1 BMP2_FILT = 1 ASPD_EN = 1 ASPD_CAL = 1; BMP1_EN = 1 BMP2_EN = 1 BMP1_FILT = 1 BMP2_FILT = 1 ASPD_EN = 1; yes; Start; Stop

9

## Dimentions

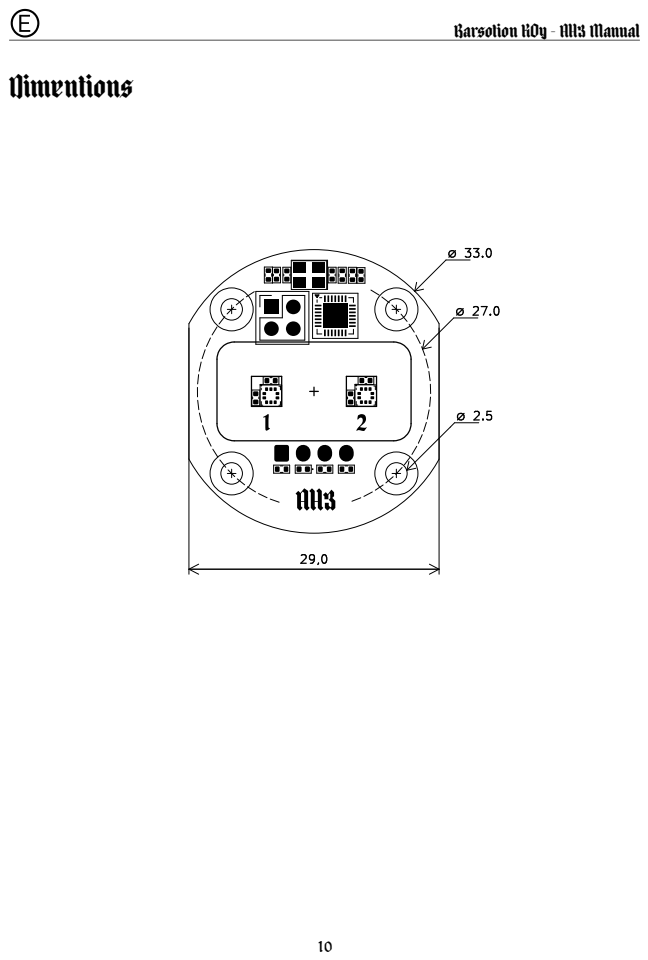
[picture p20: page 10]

Barsotion KOy - AH3 Manual

Barsotion KOy - AH3 Manual

## Revision history

Date | Modification
Mar 8, 2025 | New dimention picture, revision history addition
Jan 21, 2025 | Document creation

11

Barsotion KOy - AH3 Manual

## Contacts

If you have any questions, feel free to write via email or Telegram. Email: barsotion@yandex.ru
Telegram: @barsybarsevich

12

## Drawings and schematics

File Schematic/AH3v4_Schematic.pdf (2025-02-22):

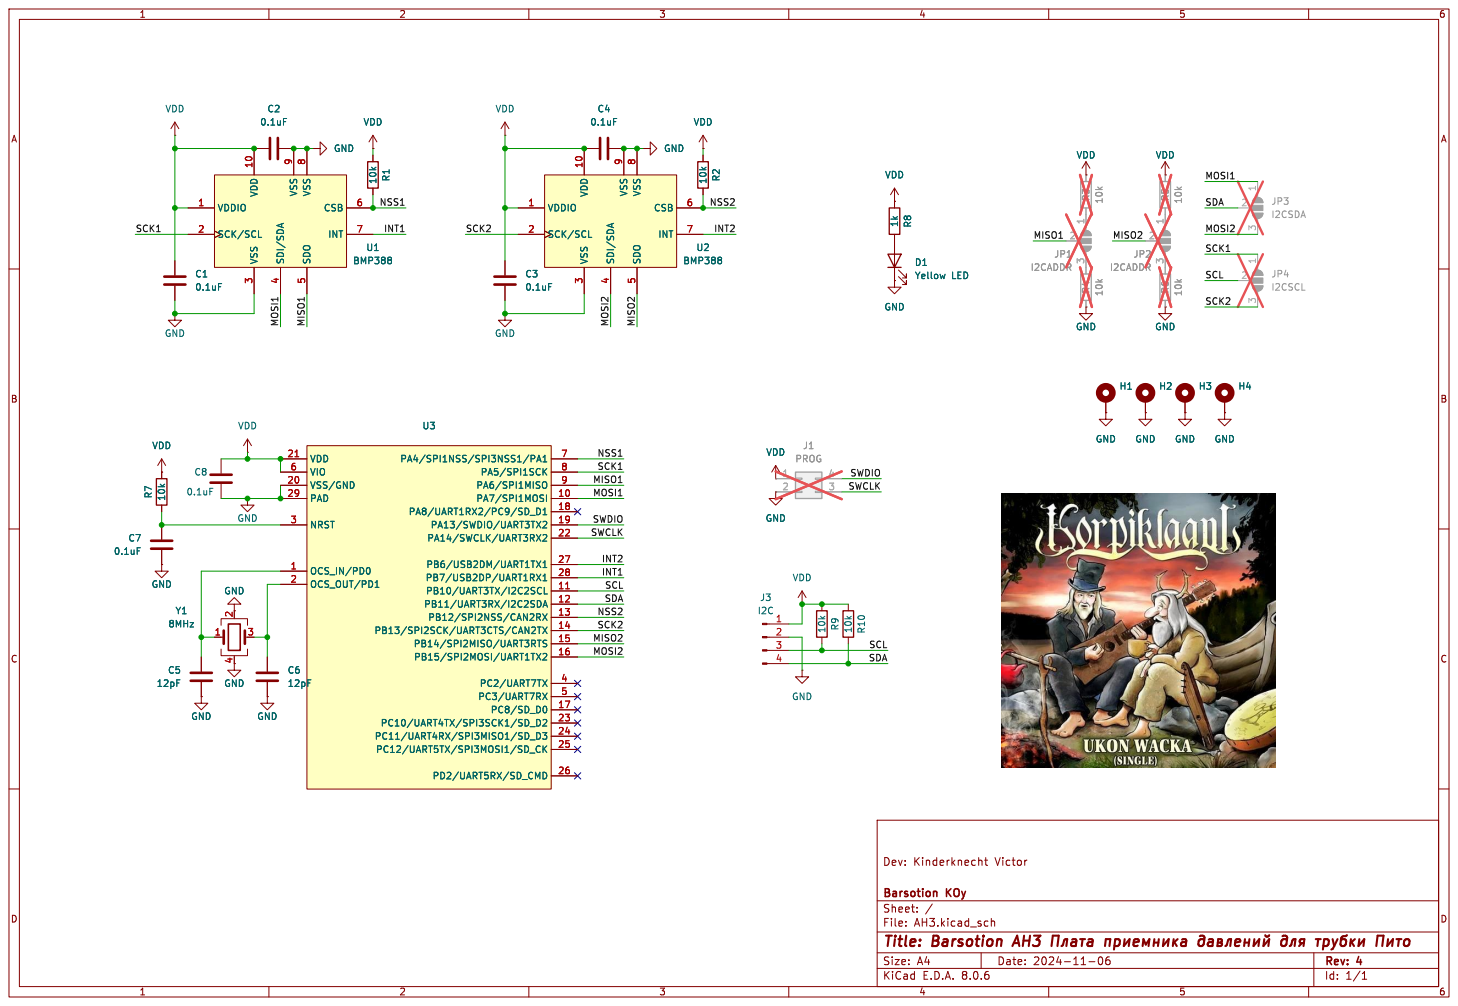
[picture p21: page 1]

9 U1 BMP388 OCS_IN/PD0 1 PA7/SPI1MOSI 10 PB10/UART3TX/I2C2SCL 11 PB11/UART3RX/I2C2SDA 12 PB12/SPI2NSS/CAN2RX 13 PB13/SPI2SCK/UART3CTS/CAN2TX 14 PB14/SPI2MISO/UART3RTS 15 PB15/SPI2MOSI/UART1TX2 16 PC8/SD_D0 17 PA8/UART1RX2/PC9/SD_D1 18 PA13/SWDIO/UART3TX2 19 OCS_OUT/PD1 2 VSS/GND 20 VDD 21 PA14/SWCLK/UART3RX2 22 PC10/UART4TX/SPI3SCK1/SD_D2 23 PC11/UART4RX/SPI3MISO1/SD_D3 24 PC12/UART5TX/SPI3MOSI1/SD_CK 25 PD2/UART5RX/SD_CMD 26 PB6/USB2DM/UART1TX1 27 PB7/USB2DP/UART1RX1 28 PAD 29 NRST 3 PC2/UART7TX 4 PC3/UART7RX 5 VIO 6 PA4/SPI1NSS/SPI3NSS1/PA1 7 PA5/SPI1SCK 8 PA6/SPI1MISO 9 U3 10k R9 VDD GND 10k R10 GND

Id: 1/1 Title: Barsotion AH3 þÿ;0B0þÿ?@85<=8:0 þÿ402;5=89 þÿ4;OþÿB@C1:8 þÿ8B>

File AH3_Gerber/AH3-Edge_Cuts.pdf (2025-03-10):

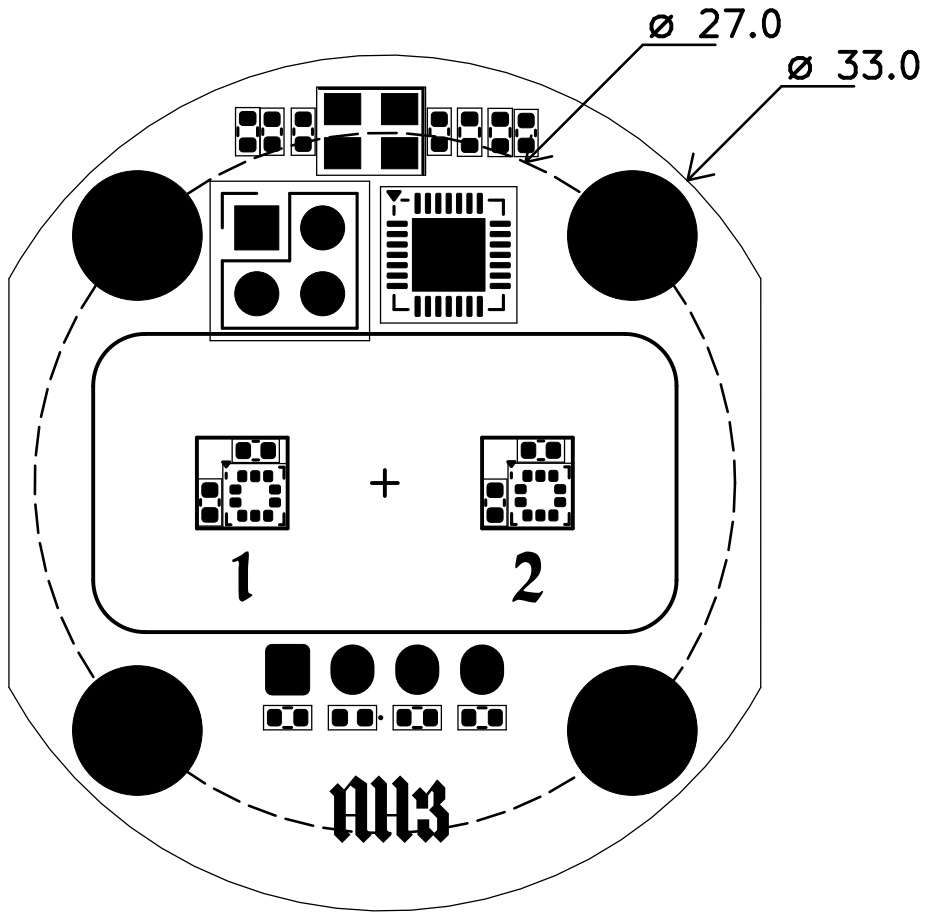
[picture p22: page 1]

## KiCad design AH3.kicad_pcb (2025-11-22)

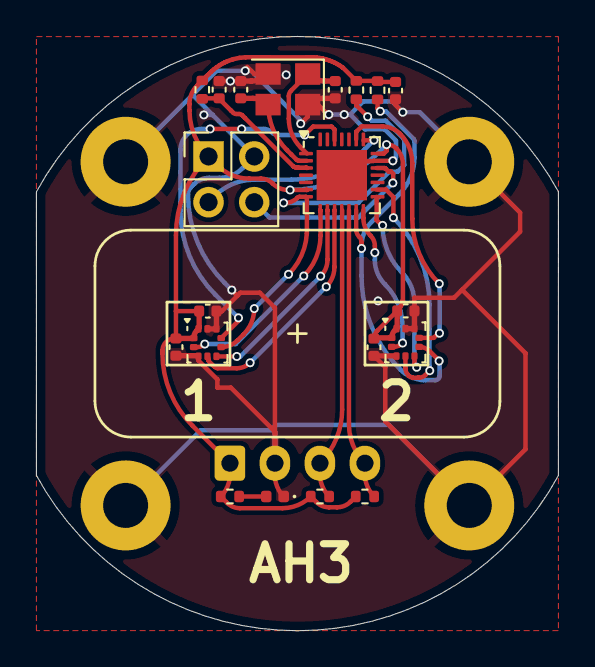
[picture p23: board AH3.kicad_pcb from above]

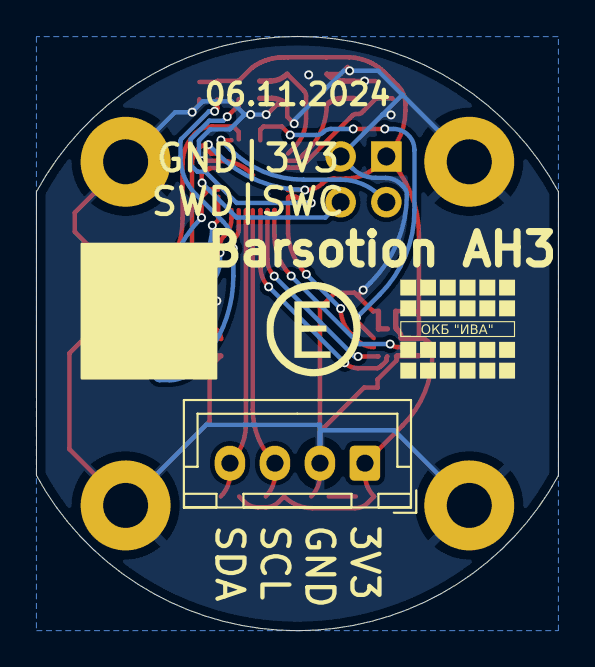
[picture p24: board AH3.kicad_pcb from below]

Board: 2 copper layers, 29.0 x 33.0 mm, 25 parts (5 on the bottom side), 20 nets.

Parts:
C1, C2, C3, C4, C7, C8: 0.1uF; C_0402_1005Metric
C5, C6: 12pF; C_0402_1005Metric
D1: Yellow LED; LED_0402_1005Metric
H1, H2, H3, H4: MountingHole_Pad; MountingHole_2.5mm_Pad
J1: PROG; PinHeader_2x02_P2.54mm_Vertical
J3: I2C; JST_XH_B4B-XH-A_1x04_P2.50mm_Vertical
R1, R2, R3, R4, R5: 10k; R_0402_1005Metric
R6: 1k; R_0402_1005Metric
U1, U2: BMP388
U3: CH32V305GBU6; QFN-28-1EP_4x4mm_P0.4mm_EP2.8x2.8mm
Y1: 8MHz; Crystal_SMD_3225-4Pin_3.2x2.5mm

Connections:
/INT1: U1.7 (INT), U3.26 (PD2/UART5RX/SD_CMD)
/INT2: U2.7 (INT), U3.23 (PC10/UART4TX/SPI3SCK1/SD_D2)
/MISO1: U1.5 (SDO), U3.9 (PA6/SPI1MISO)
/MISO2: U2.5 (SDO), U3.15 (PB14/SPI2MISO/UART3RTS)
/MOSI1: U1.4 (SDI/SDA), U3.10 (PA7/SPI1MOSI)
/MOSI2: U2.4 (SDI/SDA), U3.16 (PB15/SPI2MOSI/UART1TX2)
/NSS1: R1.1, U1.6 (CSB), U3.7 (PA4/SPI1NSS/SPI3NSS1/PA1)
/NSS2: R2.1, U2.6 (CSB), U3.13 (PB12/SPI2NSS/CAN2RX)
/SCK1: U1.2 (SCK/SCL), U3.8 (PA5/SPI1SCK)
/SCK2: U2.2 (SCK/SCL), U3.14 (PB13/SPI2SCK/UART3CTS/CAN2TX)
/SCL: J3.3, R4.1, U3.11 (PB10/UART3TX/I2C2SCL)
/SDA: J3.4, R5.1, U3.12 (PB11/UART3RX/I2C2SDA)
/SWCLK: J1.3, U3.22 (PA14/SWCLK/UART3RX2)
/SWDIO: J1.4, U3.19 (PA13/SWDIO/UART3TX2)
GND: C1.2, C2.2, C3.2, C4.2, C5.2, C6.2, C7.2, C8.2, D1.1 (K), H1.1, H2.1, H3.1, H4.1, J1.2, J3.2, U1.3 (VSS), U1.8 (VSS), U1.9 (VSS), U2.3 (VSS), U2.8 (VSS), U2.9 (VSS), U3.20 (VSS/GND), U3.29 (PAD), Y1.2, Y1.4
unnamed: D1.2 (A), R6.1
unnamed: C7.1, R3.1, U3.3 (NRST)
unnamed: C5.1, U3.1 (OCS_IN/PD0), Y1.1
unnamed: C6.1, U3.2 (OCS_OUT/PD1), Y1.3
VDD: C1.1, C2.1, C3.1, C4.1, C8.1, J1.1, J3.1, R1.2, R2.2, R3.2, R4.2, R5.2, R6.2, U1.1 (VDDIO), U1.10 (VDD), U2.1 (VDDIO), U2.10 (VDD), U3.6 (VIO), U3.21 (VDD)

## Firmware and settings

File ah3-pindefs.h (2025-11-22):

#pragma once

#define AH3_I2C_ADDRESS			0x02
#define AH3_WHO_AM_I_VALUE		0x74
#define AH3_SOFT_REVISION_VALUE	0x02
/* Interface defines */
#define AH3_BMP1_SPI_HOST		SPI1
#define AH3_BMP1_SPI_PORT		GPIOA
#define AH3_BMP1_INT_PORT		GPIOD
#define AH3_BMP1_MISO_PIN		GPIO_Pin_6
#define AH3_BMP1_MOSI_PIN		GPIO_Pin_7
#define AH3_BMP1_SCK_PIN		GPIO_Pin_5
#define AH3_BMP1_NSS_PIN		GPIO_Pin_4
#define AH3_BMP1_INT_PIN		GPIO_Pin_2
#define AH3_BMP2_SPI_HOST		SPI2
#define AH3_BMP2_SPI_PORT		GPIOB
#define AH3_BMP2_INT_PORT		GPIOC
#define AH3_BMP2_MISO_PIN		GPIO_Pin_14
#define AH3_BMP2_MOSI_PIN		GPIO_Pin_15
#define AH3_BMP2_SCK_PIN		GPIO_Pin_13
#define AH3_BMP2_NSS_PIN		GPIO_Pin_12
#define AH3_BMP2_INT_PIN		GPIO_Pin_10
#define AH3_I2C_SLAVE_HOST		I2C2
#define AH3_I2C_SLAVE_SCL_PIN	GPIO_Pin_10
#define AH3_I2C_SLAVE_SCL_PORT	GPIOB
#define AH3_I2C_SLAVE_SDA_PIN	GPIO_Pin_11
#define AH3_I2C_SLAVE_SDA_PORT	GPIOB
/* Register map */
#define AH3_WHO_AM_I			0x00
#define AH3_SOFT_REVISION		0x01
#define AH3_ERR					0x02
#define AH3_CONFIG				0x03
#define AH3_STATUS				0x04
#define AH3_TEMP1_0				0x05
#define AH3_TEMP1_1				0x06
#define AH3_TEMP1_2				0x07
#define AH3_TEMP1_3				0x08
#define AH3_PRES1_0				0x09
#define AH3_PRES1_1				0x0A
#define AH3_PRES1_2				0x0B
#define AH3_PRES1_3				0x0C
#define AH3_TEMP2_0				0x0D
#define AH3_TEMP2_1				0x0E
#define AH3_TEMP2_2				0x0F
#define AH3_TEMP2_3				0x10
#define AH3_PRES2_0				0x11
#define AH3_PRES2_1				0x12
#define AH3_PRES2_2				0x13
#define AH3_PRES2_3				0x14
#define AH3_ASPEED_0			0x15
#define AH3_ASPEED_1			0x16
#define AH3_ASPEED_2			0x17
#define AH3_ASPEED_3			0x18
#define AH3_ALT_0				0x19
#define AH3_ALT_1				0x1A
#define AH3_ALT_2				0x1B
#define AH3_ALT_3				0x1C
#define AH3_VSPEED_0			0x1D
#define AH3_VSPEED_1			0x1E
#define AH3_VSPEED_2			0x1F
#define AH3_VSPEED_3			0x20
#define AH3_CONFIG2				0x21
#define AH3_OFFSET_BMP1			0x22
#define AH3_OFFSET_BMP1_0		0x22
#define AH3_OFFSET_BMP1_1		0x23
#define AH3_OFFSET_BMP1_2		0x24
#define AH3_OFFSET_BMP1_3		0x25
#define AH3_OFFSET_BMP2			0x26
#define AH3_OFFSET_BMP2_0		0x27
#define AH3_OFFSET_BMP2_1		0x28
#define AH3_OFFSET_BMP2_2		0x29
#define AH3_OFFSET_BMP2_3		0x2A
/* Register bits */
#define AH3_ERR_BMP1_INIT		1<<0
#define AH3_ERR_BMP2_INIT		1<<1
#define AH3_ERR_I2C				1<<2
#define AH3_ERR_BMP1_DATA		1<<3
#define AH3_ERR_BMP2_DATA		1<<4
/*  */
#define AH3_CFG_BMP1_EN			1<<0
#define AH3_CFG_BMP2_EN			1<<1
#define AH3_CFG_BMP1_FILT		1<<2
#define AH3_CFG_BMP2_FILT		1<<3
#define AH3_CFG_BMP1_CALIB		1<<4
#define AH3_CFG_BMP2_CALIB		1<<5
#define AH3_CFG_ASPEED_EN		1<<6
#define AH3_CFG_ASPEED_CAL		1<<7
//
#define AH3_STATUS_BMP1_DRDY	1<<0
#define AH3_STATUS_BMP2_DRDY	1<<1
#define AH3_STATUS_ASPEED_DRDY	1<<6
#define AH3_STATUS_BUSY			1<<7

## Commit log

2025-03-10 readme update
    [AH3.kicad_pcb]
2025-11-22 kicad files addition
    [AH3.kicad_pcb, AH3.kicad_sch]
2025-11-22 actual schematic addition
2025-11-22 adding actual BOM
    [Barsotion_AH3_BOM.csv]
